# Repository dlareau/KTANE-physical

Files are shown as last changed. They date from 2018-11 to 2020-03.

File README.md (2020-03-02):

# KTANE-physical
A physical version of the game "Keep Talking and Nobody Explodes". 
Not a real bomb.

## Update: 3/2/2020
I am currently making progress on Version 2 of KTANE-physical. There are some major under the hood things that need to be done (such as replacing DSerial and designing PCBs) before new progress can be made. The "most-working" commit for V1 is currently commit aa4ee07, which is what should be used for attempts at replicating V1. 

### Planned Modules

| Module Name | Sketched | Coded | Made |
| --- |:---:|:---:|:---:|
| Memory |:heavy_check_mark:|:heavy_check_mark:|:heavy_check_mark:|
| Simon Says |:heavy_check_mark:|:heavy_check_mark:|:heavy_check_mark:|
| Wires |:heavy_check_mark:|:heavy_check_mark:|:heavy_check_mark:|
| Morse Code |:heavy_check_mark:|:heavy_check_mark:|:heavy_check_mark:|
| The Button |:heavy_check_mark:| | |
| Maze | | | |
| Password |:heavy_check_mark:|:heavy_check_mark:| |
| Keypad (symbols) |:heavy_check_mark:| | |
| Switches |:heavy_check_mark:|:heavy_check_mark:|:heavy_check_mark:|
| Letter Keys |:heavy_check_mark:| | |
| Twobits |:heavy_check_mark:| | |
| Crazy Talk |:heavy_check_mark:| | |
| Connection Check |:heavy_check_mark:| | |
| Venting Gas | | | |
| Capacitor Discharge | | | |
| Knobs | | | |

The general plan is for each module to contain an ATmega328p which will handle 
running all of the local I/O and communicate with a controller module
(also an Atmega328p).

### Intermodule communication (DSerial)

Many modules need to act as an I2C master to display devices or sensors, and
an unfortunate number of display devices have locked I2C addresses. This means
that I2C isn't feasibly a possibility for intermodule communication. Desiring
a solution that didn't require running a dedicated wire from each module to the
controller module, I opted for a multidrop serial bus. 

The downside of a multidrop bus is that some form of arbitration is
needed to stop bus contention. This is solved by the DSerial library I wrote
for this project. The DSerial library implements a layer on top of any Arduino
[Stream](http://www.arduino.cc/reference/en/language/functions/communication/stream/) 
interface. The DSerial library operates with one master and many clients and 
in addition to managing bus contention, it makes a best effort to guarantee
that each message will be delivered to the desired client exactly once. To this
end, it implements message-level parity checking, a pre-defined number of 
retries upon failed delivery, and can determine which clients are alive on the
network.

Currently DSerial has two major limitations: 
- Due to being comprised of entirely non-blocking calls, it requires whatever 
is using it to periodically and continuously call the doSerial method.

- It currently only allows the transmission of bytes with values between 0x01
and 0x7F inclusive. Future implementations will hopefully allow for the
transmission of null bytes and bytes above 0x7F.

### Module behavior and templates

Common functionality across modules has been extracted out into the KTANECommon
library. The library handles the sending/receiving of strikes, solves and
configuration data between solvable modules and the controller module. The 
library also handles the controller waiting for modules to setup and the modules
easily querying various aspects of the configuration data. The KTANECommon
library suffers from the same upside/downside as the DSerial library in that it
requires the code to periodically and continuously call the interpretData
function. 

A template for modules can be found [here](modules/exampleModule/example.ino).

### The Hardware

The current iteration of the hardware is Version 1. V1 consists of one
controller module and up to five swappable, playable modules in a suitcase as
an enclosure. The modules connect to the main bus through directional 
male/female 4 pin plugs intended for LED strips. The major limiting factor
imposed by V1 is the 1.25" height limit on user interface protrusions needed
to allow the case to close.

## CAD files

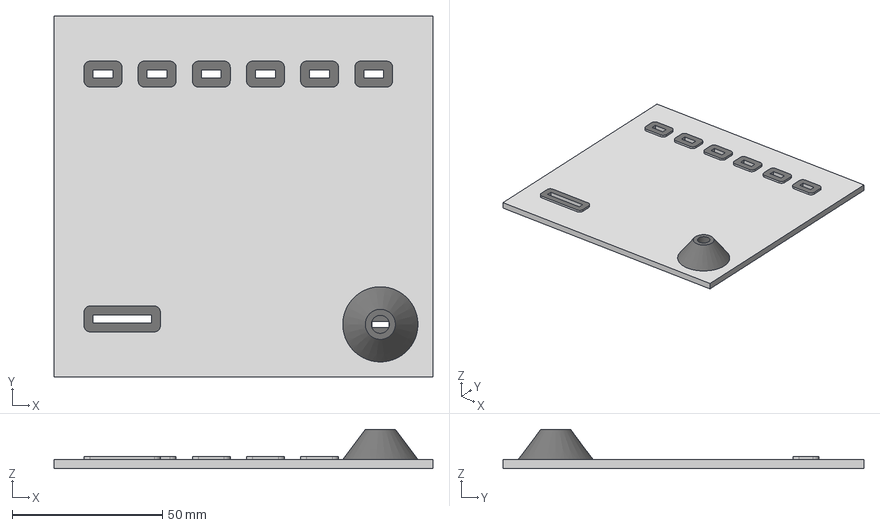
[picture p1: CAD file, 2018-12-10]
modules/basicWiresModule/front_plate_wires.stp
126.0 x 120.0 x 13.0 mm

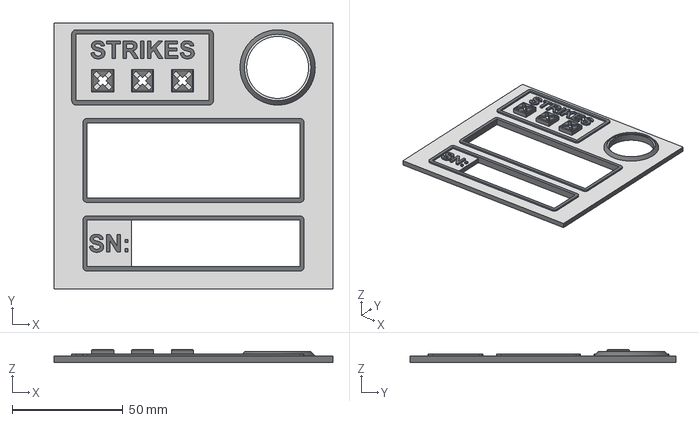
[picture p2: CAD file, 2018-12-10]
modules/controllerModule/front_plate_controller.stp
126.0 x 120.0 x 6.00 mm

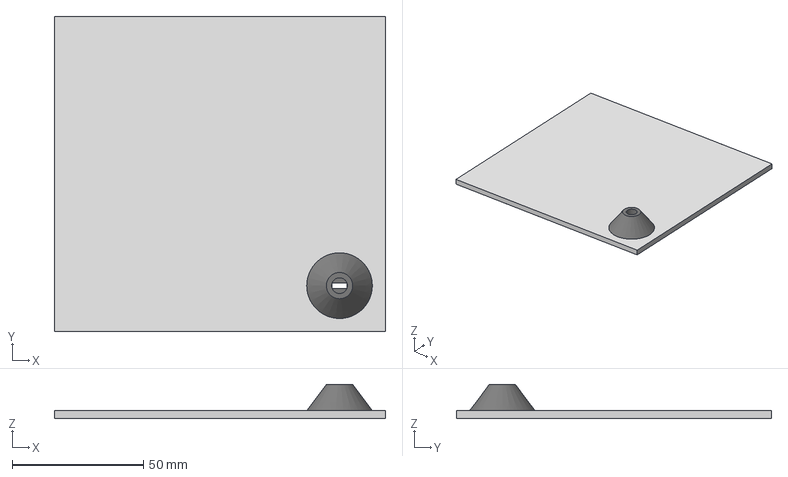
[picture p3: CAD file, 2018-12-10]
modules/exampleModule/front_face_example.stp
126.0 x 120.0 x 13.0 mm

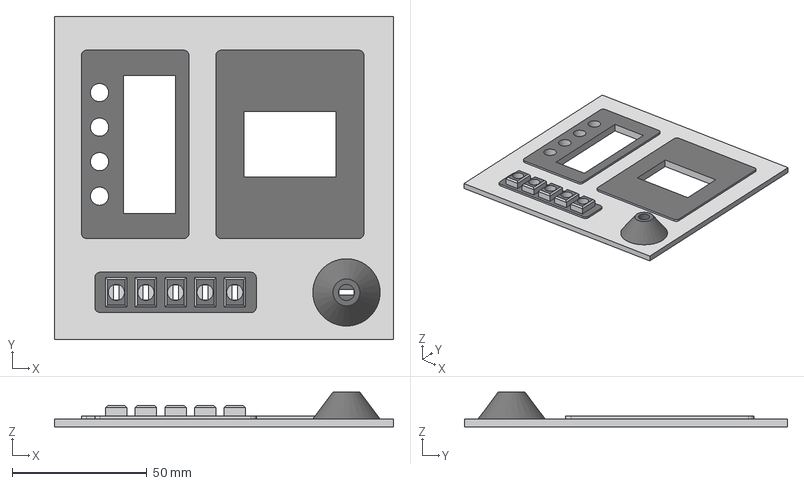
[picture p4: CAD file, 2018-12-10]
modules/memoryModule/front_plate_memory.stp
126.0 x 120.0 x 13.0 mm

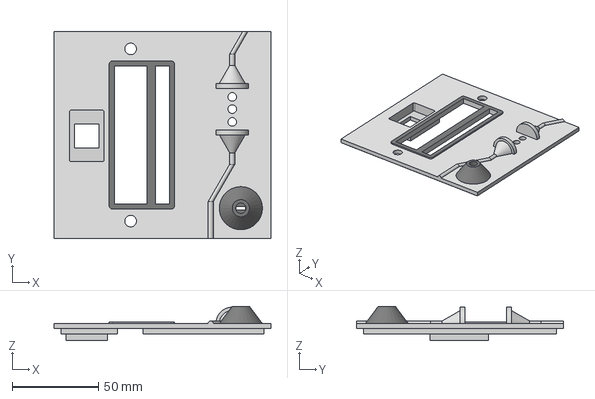
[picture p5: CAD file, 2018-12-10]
modules/morseCodeModule/front_plate_morse.stp
126.0 x 120.0 x 20.0 mm

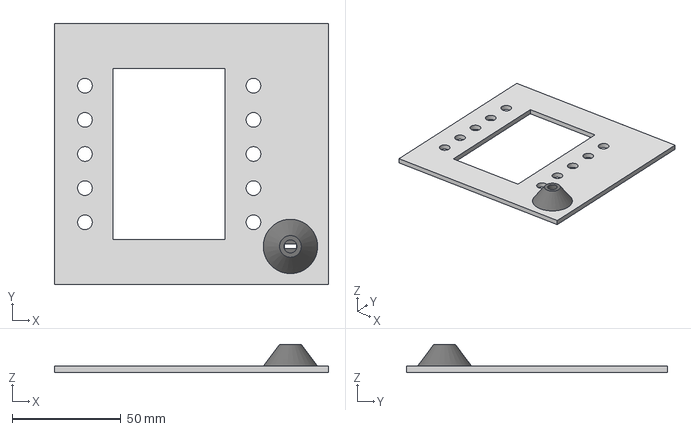
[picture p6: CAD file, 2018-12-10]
modules/passwordModule/front_plate_password.stp
126.0 x 120.0 x 13.0 mm

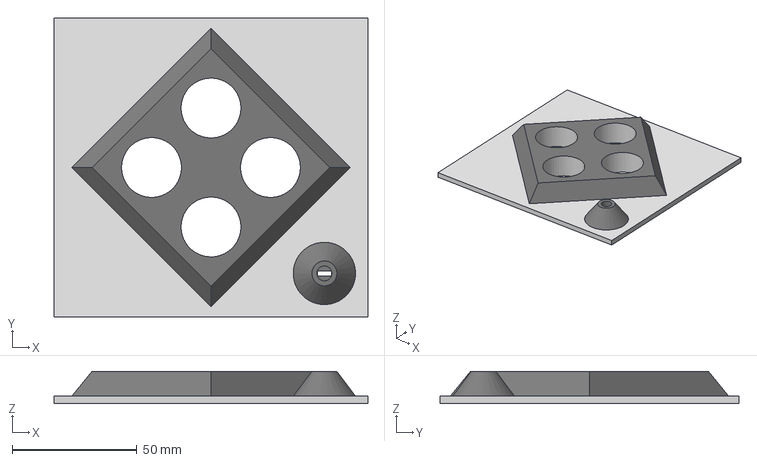
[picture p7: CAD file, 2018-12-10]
modules/simonSaysModule/front_plate_simon.stp
126.0 x 120.0 x 13.0 mm

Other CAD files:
modules/switchesModule/front_plate_switches.stp
modules/basicWiresModule/front_plate_wires.stl
modules/controllerModule/front_plate_controller.stl
modules/exampleModule/front_face_example.stl
modules/memoryModule/front_plate_memory.stl
modules/morseCodeModule/front_plate_morse.stl
modules/passwordModule/front_plate_password.stl
modules/simonSaysModule/front_plate_simon.stl
modules/switchesModule/front_plate_switches.stl

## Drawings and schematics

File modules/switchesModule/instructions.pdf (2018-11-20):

## On the Subject of Switches

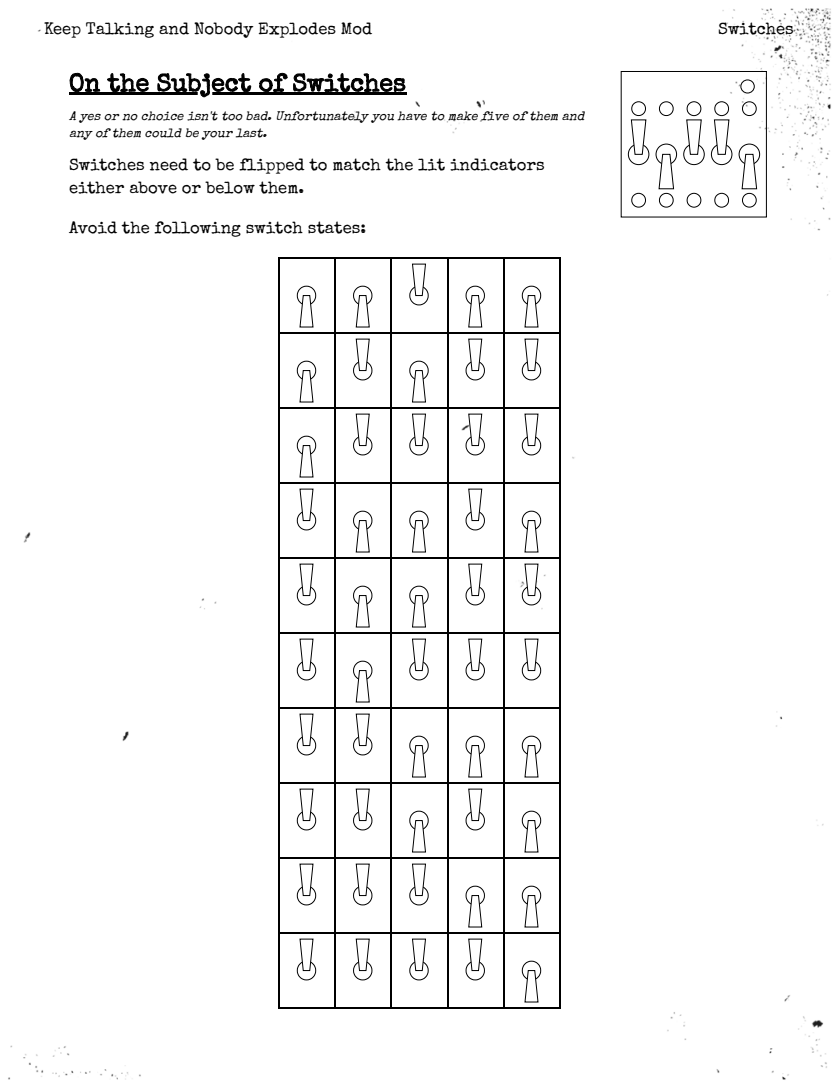
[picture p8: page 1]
Keep Talking and Nobody Explodes Mod; Switches

A yes or no choice isn't too bad. Unfortunately you have to make five of them and
any of them could be your last.
Switches need to be flipped to match the lit indicators
either above or below them.

Avoid the following switch states:

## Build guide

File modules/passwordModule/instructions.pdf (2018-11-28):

## On the Subject of Passwords

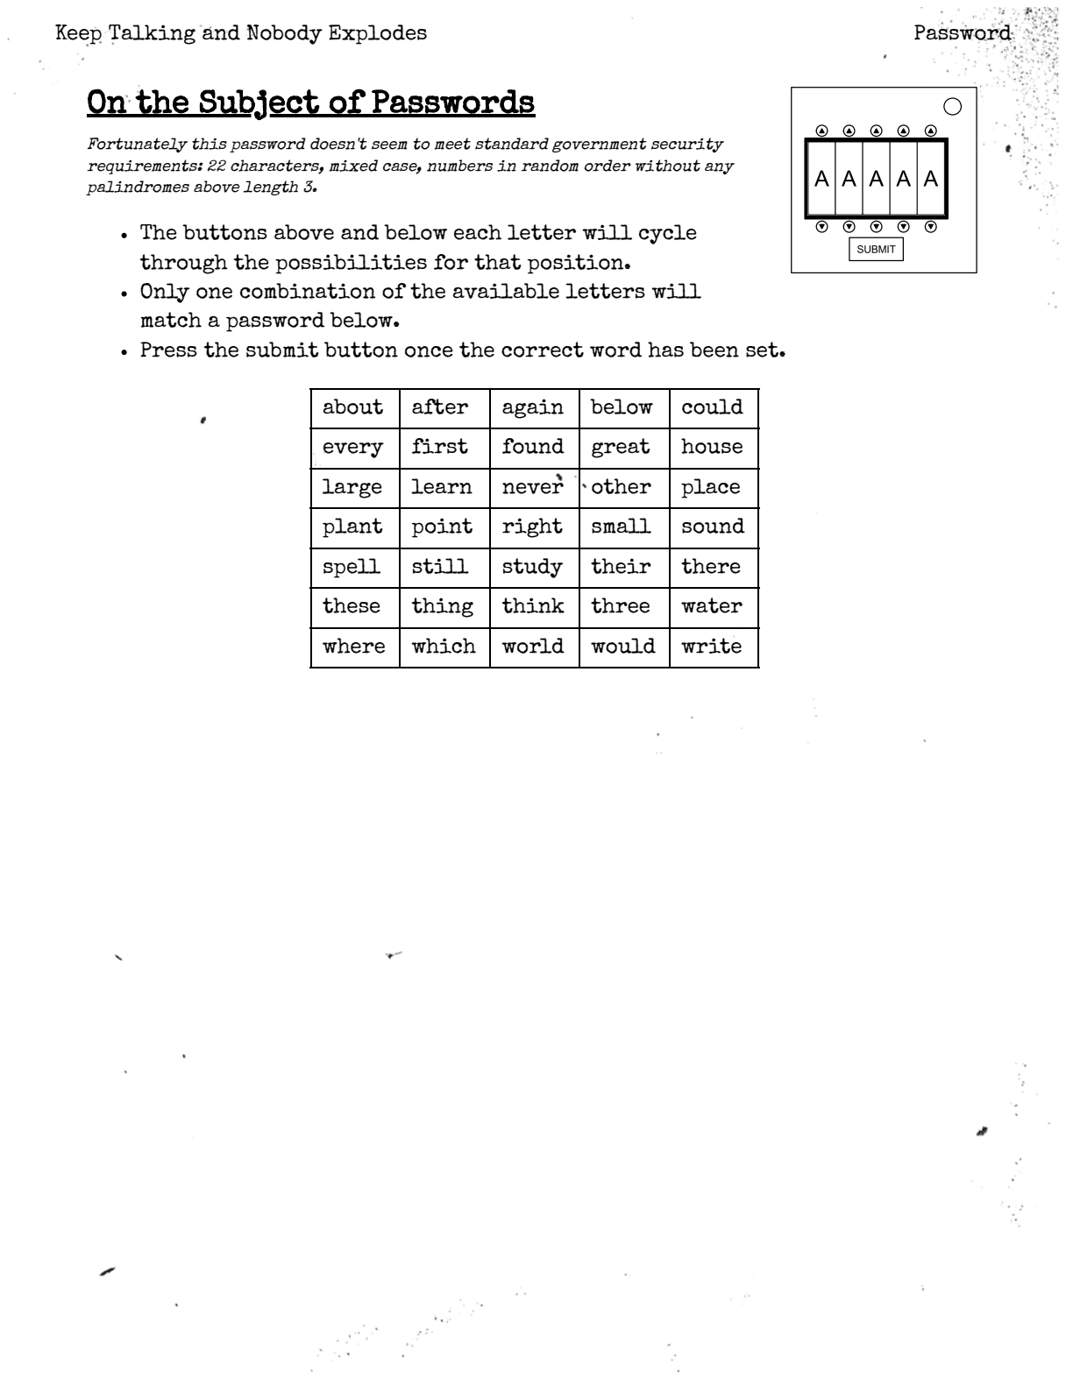
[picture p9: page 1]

Fortunately this password doesn't seem to meet standard government security requirements: 22 characters, mixed case, numbers in random order without any palindromes above length 3.

The buttons above and below each letter will cycle through the possibilities for that position.
Only one combination of the available letters will
match a password below.
Press the submit button once the correct word has been set.
about | after | again | below | could
every | first | found | great | house
large | learn | never | other | place
plant | point | right | small | sound
spell | still | study | their | there
these | thing | think | three | water
where | which | world | would | write
Keep Talking and Nobody Explodes | Password

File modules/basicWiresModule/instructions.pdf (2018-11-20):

## On the Subject of Wires

Wires are the lifeblood of electronics! Wait, no, electricity is the lifeblood. Wires are more like the arteries. The veins? No matter…

A wire module can have 3-6 wires on it.
Only the one correct wire needs to be cut to disarm the module.
Wire ordering begins with the first on the top.

3 wires:
If there are no red wires, cut the second wire.
Otherwise, if the last wire is white, cut the last wire.
Otherwise, if there is more than one blue wire, cut the last blue wire. Otherwise, cut the last wire.

4 wires:
If there is more than one red wire and the last digit of the serial number is odd, cut the last red wire.
Otherwise, if the last wire is yellow and there are no red wires, cut the first wire.
Otherwise, if there is exactly one blue wire, cut the first wire.
Otherwise, if there is more than one yellow wire, cut the last wire. Otherwise, cut the second wire.

5 wires:
If the last wire is black and the last digit of the serial number is odd, cut the fourth wire.
Otherwise, if there is exactly one red wire and there is more than one yellow wire, cut the first wire.
Otherwise, if there are no black wires, cut the second wire.
Otherwise, cut the first wire.

6 wires:
If there are no yellow wires and the last digit of the serial number is odd, cut the third wire.
Otherwise, if there is exactly one yellow wire and there is more than one white wire, cut the fourth wire.
Otherwise, if there are no red wires, cut the last wire.
Otherwise, cut the fourth wire.
Keep Talking and Nobody Explodes | Wires

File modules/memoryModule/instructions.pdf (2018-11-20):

## On the Subject of Memory

Memory is a fragile thing but so is everything else when a bomb goes off, so pay attention!

Press the correct button to progress the module to the next stage. Complete all stages to disarm the module. Pressing an incorrect button will reset the module back to stage 1.
Button positions are ordered from left to right.

Stage 1:
If the display is 1, press the button in the second position. If the display is 2, press the button in the second position. If the display is 3, press the button in the third position. If the display is 4, press the button in the fourth position.

Stage 2:
If the display is 1, press the button labeled "4".
If the display is 2, press the button in the same position as you pressed in stage 1. If the display is 3, press the button in the first position.
If the display is 4, press the button in the same position as you pressed in stage 1.

Stage 3:
If the display is 1, press the button with the same label you pressed in stage 2.
If the display is 2, press the button with the same label you pressed in stage 1. If the display is 3, press the button in the third position.
If the display is 4, press the button labeled "4".

Stage 4:
If the display is 1, press the button in the same position as you pressed in stage 1. If the display is 2, press the button in the first position.
If the display is 3, press the button in the same position as you pressed in stage 2. If the display is 4, press the button in the same position as you pressed in stage 2.

Stage 5:
If the display is 1, press the button with the same label you pressed in stage 1.
If the display is 2, press the button with the same label you pressed in stage 2. If the display is 3, press the button with the same label you pressed in stage 4. If the display is 4, press the button with the same label you pressed in stage 3.
Keep Talking and Nobody Explodes | Memory

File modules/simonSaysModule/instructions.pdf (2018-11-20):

## On the Subject of Simon Says

This is like one of those toys you played with as a kid where you have to match the pattern that appears, except this one is a knockoff that was probably purchased at a dollar store.

1. One of the four colored buttons will flash.
2. Using the correct table below, press the button with the
corresponding color.
3. The original button will flash, followed by another. Repeat this sequence in order using the color mapping.
4. The sequence will lengthen by one each time you correctly enter a sequence until the module is disarmed.

If the serial number contains a vowel:

Red Flash | Blue Flash | Green Flash | Yellow Flash
Button to press: | No Strikes | Blue | Red | Yellow | Green
| 1 Strike | Yellow | Green | Blue | Red
| 2+ Strikes | Green | Red | Yellow | Blue

If the serial number does not contain a vowel:

Red Flash | Blue Flash | Green Flash | Yellow Flash
Button to press: | No Strikes | Blue | Yellow | Green | Red
| 1 Strike | Red | Blue | Yellow | Green
| 2+ Strikes | Yellow | Green | Blue | Red
Keep Talking and Nobody Explodes | Simon Says

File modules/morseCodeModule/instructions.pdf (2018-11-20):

## On the Subject of Morse Code

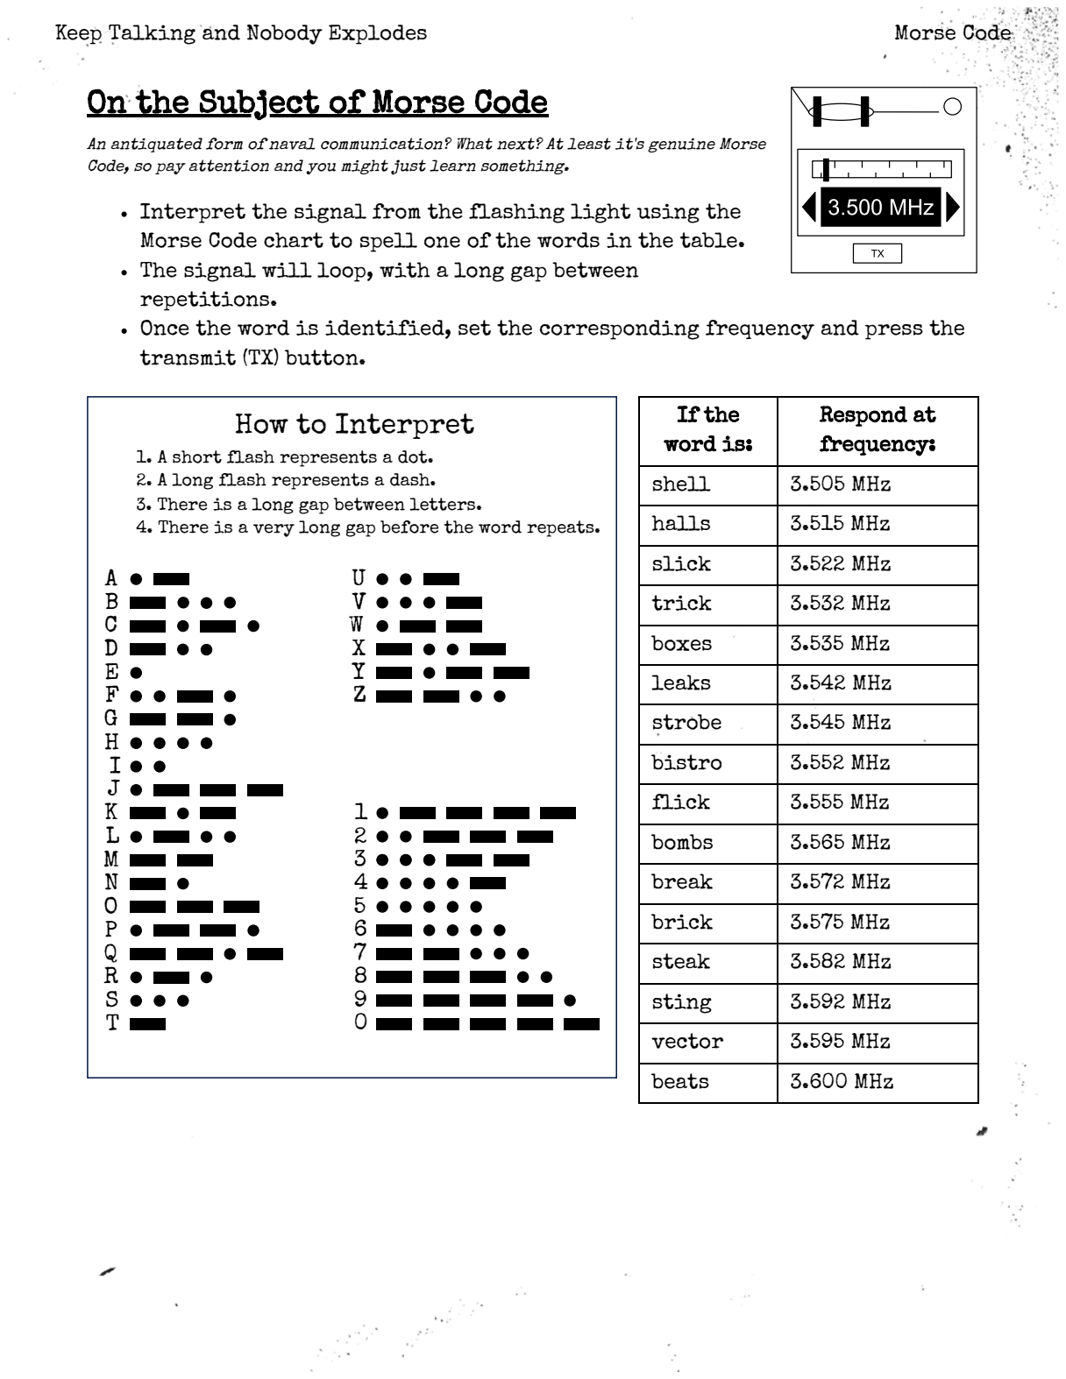
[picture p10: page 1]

## How to Interpret

1. A short flash represents a dot.
2. A long flash represents a dash.
3. There is a long gap between letters.
4. There is a very long gap before the word repeats.

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
An antiquated form of naval communication? What next? At least it's genuine Morse Code, so pay attention and you might just learn something.

Interpret the signal from the flashing light using the Morse Code chart to spell one of the words in the table.
The signal will loop, with a long gap between
repetitions.
Once the word is identified, set the corresponding frequency and press the transmit (TX) button.
If the word is: | Respond at frequency:
shell | 3.505 MHz
halls | 3.515 MHz
slick | 3.522 MHz
trick | 3.532 MHz
boxes | 3.535 MHz
leaks | 3.542 MHz
strobe | 3.545 MHz
bistro | 3.552 MHz
flick | 3.555 MHz
bombs | 3.565 MHz
break | 3.572 MHz
brick | 3.575 MHz
steak | 3.582 MHz
sting | 3.592 MHz
vector | 3.595 MHz
beats | 3.600 MHz
Keep Talking and Nobody Explodes | Morse Code

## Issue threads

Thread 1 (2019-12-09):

Any progress on this project?

cyberbit, 2019-12-09:
This is a neat project! A hardware version of KTANE is something I have been considering doing ever since watching the game for the first time many years ago. Are you still actively developing this? Any hints to the design of the hardware modules? I'd love to see a real working version!

dlareau, 2019-12-09:
Yeah, I took a long break on it, but I am actually just starting back up on the next version.
I don't know which method you stumbled upon this repo through, but if it wasn't the imgur album or my website, you can see the photos of V1 here: https://imgur.com/a/J6HdM0v#w1oaDi1 or here:

Basically all of the hardware for version 1 was point to point soldering, arduino nanos, and some stripboard where needed. (here is a photo of the back of 4 modules: https://photos.app.goo.gl/ooWz5mRqGPEx7vju6) Version 2 that I'm working on now will have PCBs, the design files for which will be included here once designed.

Version 1 was also very fragile, in that while things were swappable, yanking on a module would likely destroy it. Version 2 will also greatly improve upon the plug and play nature of the modules, making it so that anybody can swap out modules without the worry of breaking something.

If you have any other questions I'd love to chat.

cyberbit, 2019-12-13:
Thanks for the reply! That looks slick.

A part of me wonders about the feasibility of adding "parameterization" modules (battery slots, indicator lights, etc.) that are permanent around the edges of the device. I've got lots of other ideas spinning in my head but I can't nail them down.

dlareau, 2019-12-13:
Version 2 is already a bit ahead of you :)

While not quite in line with the original game layout, those 3 left-side boxes are for swappable items such as batteries, indicators, and ports.
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

olbrichj, 2020-02-05:
This really looks neat! I was looking at the game for my gaming round. Searching for something more immersive I found this.

Some remarks/ideas:
- The case and modules could be 3d printed. This would stabilize the module structure and improve swappability
- Will there be a serialnumber display at the side?

dlareau, 2020-02-06:
Thanks!

Replies in order:
- Serial number on the side was harder, so I ended up putting it in the extra space of the master/timer module, you can see it in [the gallery](https://imgur.com/a/J6HdM0v#w1oaDi1).
- There will be the option to connect multiple full units together, because of the way I've decided to architect things, the whole system runs off of a 4 wire bus that provides power and data, meaning hooking up a whole second case would be as easy as connecting those 4 wires between two cases. What connector that uses and where it will be haven't been sorted out yet.
- This project was meant to mimic the game and it's feel as much as possible. To that end, the modules were made to be in scale of the game by comparing against things like the ports/batteries on the side of the case. Plus, I can say from experience that things turned out well, when playing all of the elements felt accurate and very fun to interact with. Lastly, turns out I needed a lot of that space for electronics anyway, so it was all good.
- Similar to the above point, I was aiming for accuracy, so the 2x3 layout of the game felt right. The good news is that v2 is much more modular and includes 3d prints for both the module and the "module shell" which the module nestles into, so if someone else wanted to it would be really easy to just design a different holder for a bunch of module shells. Plus, I always imagined that if you wanted more than the 6+3, you could just hook up another case like talked about above.

rubenvt, 2020-04-17:
Great job done! I love this project and think the V2 with PCB would be great, because I have no idea how I would accomplish making V1 at this moment without a good diagram for each module to know where to connect wires to and which components to use :-) if you have any details about it, it would make my day. keep up the good work

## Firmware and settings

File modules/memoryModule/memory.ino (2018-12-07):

#include "DSerial.h"
#include "KTANECommon.h"
#include <NeoICSerial.h>

#define DATA_IN_PIN 11
#define LOAD_PIN 12
#define CLOCK_PIN 13
#define DISP_SINGLE(x,y) maxSingle((x), (y), LOAD_PIN, CLOCK_PIN, DATA_IN_PIN)

#define BUTTON1_PIN 14
#define BUTTON2_PIN 15
#define BUTTON3_PIN 16
#define BUTTON4_PIN 17

#define LED1_PIN 19
#define LED2_PIN 18
#define LED3_PIN 7
#define LED4_PIN 6
#define LED5_PIN 5

NeoICSerial serial_port;
DSerialClient client(serial_port, MY_ADDRESS);
KTANEModule module(client, 3, 4);

uint8_t bottom_nums[5][4];
uint8_t top_nums[5];
uint8_t buttons_to_press[5];
int stage = 0;

// Has 6 elements to stop overflow when you win
int led_pins[6] = {LED1_PIN, LED2_PIN, LED3_PIN, LED4_PIN, LED5_PIN, LED5_PIN};

byte max7219_reg_decodeMode  = 0x09;
byte max7219_reg_intensity   = 0x0a;
byte max7219_reg_scanLimit   = 0x0b;
byte max7219_reg_shutdown    = 0x0c;
byte max7219_reg_displayTest = 0x0f;

int constants[5] = {
  0b10111110, // 0
  0b00010010, // 1
  0b11011100, // 2
  0b11011010, // 3
  0b01110010 // 4
};

int digits[5] = {3, 8, 6, 5, 4};

uint8_t getIndexFromNumber(uint8_t *buttons, uint8_t num){
  for(int i = 0; i < 4; i++) {
    if(buttons[i] == num) {
      return i;
    }
  }
  return 255;
}

void updateDisplays() {
  DISP_SINGLE(5, constants[bottom_nums[stage][0]]);
  DISP_SINGLE(6, constants[bottom_nums[stage][1]]);
  DISP_SINGLE(8, constants[bottom_nums[stage][2]]);
  DISP_SINGLE(3, constants[bottom_nums[stage][3]]);
  DISP_SINGLE(4, constants[top_nums[stage]]);
  for(int i = 0; i < 5; i++) {
    digitalWrite(led_pins[i], LOW);
  }
  for(int i = 0; i <= stage; i++) {
    digitalWrite(led_pins[i], HIGH);
  }
}

void displayWaitingScreen() {

  // needs to delay for a total of 2500
  for(int i = 0; i < 5; i++) {
    DISP_SINGLE(digits[i], 0);
    delayWithUpdates(module, 100);
  }
  for(int i = 0; i < 15; i++){
    for(int j = 0; j < 5; j++) {
      DISP_SINGLE(digits[j], 1 << ((i+j)%7));
    }
    delayWithUpdates(module, 100);
  }
  for(int i = 0; i < 5; i++) {
    DISP_SINGLE(digits[i], 0);
  }
  delayWithUpdates(module, 500);
}

void generateRandomNumbers() {
  int r1, r2;
  uint8_t temp;
  for(int i = 0; i < 5; i++){
    bottom_nums[i][0] = 1;
    bottom_nums[i][1] = 2;
    bottom_nums[i][2] = 3;
    bottom_nums[i][3] = 4;

    for(int j = 0; j < 20; j++){
      r1 = random(0, 4);
      r2 = random(0, 4);
      temp = bottom_nums[i][r1];
      bottom_nums[i][r1] = bottom_nums[i][r2];
      bottom_nums[i][r2] = temp;
    }

    top_nums[i] = random(1,5);
  }

  switch(top_nums[0]) {
    case(1):
      buttons_to_press[0] = 1; // Second Position
      break;
    case(2):
      buttons_to_press[0] = 1; // Second Position
      break;
    case(3):
      buttons_to_press[0] = 2; // Third Position
      break;
    case(4):
      buttons_to_press[0] = 3; // Fourth Position
      break;
  }
  switch(top_nums[1]) {
    case(1):
      // Button labeled 4
      buttons_to_press[1] = getIndexFromNumber(bottom_nums[1], 4);
      break;
    case(2):
      buttons_to_press[1] = buttons_to_press[0]; // Same position as stage 1
      break;
    case(3):
      buttons_to_press[1] = 0; // First Position
      break;
    case(4):
      buttons_to_press[1] = buttons_to_press[0]; // Same position as stage 1
      break;
  }
  switch(top_nums[2]) {
    case(1):
      // Same label as stage 2
      buttons_to_press[2] = getIndexFromNumber(bottom_nums[2], bottom_nums[1][buttons_to_press[1]]);
      break;
    case(2):
      // Same label as stage 1
      buttons_to_press[2] = getIndexFromNumber(bottom_nums[2], bottom_nums[0][buttons_to_press[0]]);
      break;
    case(3):
      buttons_to_press[2] = 2;  // Third Position
      break;
    case(4):
      // Button labeled 4
      buttons_to_press[2] = getIndexFromNumber(bottom_nums[2], 4) ;
      break;
  }
  switch(top_nums[3]) {
    case(1):
      buttons_to_press[3] = buttons_to_press[0]; // Same position as stage 1
      break;
    case(2):
      buttons_to_press[3] = 0;  // First Position
      break;
    case(3):
      buttons_to_press[3] = buttons_to_press[1]; // Same position as stage 2
      break;
    case(4):
      buttons_to_press[3] = buttons_to_press[1]; // Same position as stage 2
      break;
  }
  switch(top_nums[4]) {
    case(1):
      // Same label as stage 1
      buttons_to_press[4] = getIndexFromNumber(bottom_nums[4], bottom_nums[0][buttons_to_press[0]]);
      break;
    case(2):
      // Same label as stage 2
      buttons_to_press[4] = getIndexFromNumber(bottom_nums[4], bottom_nums[1][buttons_to_press[1]]);
      break;
    case(3):
      // Same label as stage 3
      buttons_to_press[4] = getIndexFromNumber(bottom_nums[4], bottom_nums[2][buttons_to_press[3]]);
      break;
    case(4):
      // Same label as stage 4
      buttons_to_press[4] = getIndexFromNumber(bottom_nums[4], bottom_nums[3][buttons_to_press[2]]);
      break;
  }

  // for(int i = 0; i < 5; i++) {
  //   Serial.println("");
  //   Serial.println("");
  //   Serial.println(top_nums[i]);
  //   Serial.println(buttons_to_press[i]);
  //   for(int j = 0; j < 4; j++){
  //     Serial.print(bottom_nums[i][j]);
  //   }
  // }
}

void setup() {
  serial_port.begin(19200);
  Serial.begin(19200);

  pinMode(DATA_IN_PIN, OUTPUT);
  pinMode(LOAD_PIN, OUTPUT);
  pinMode(CLOCK_PIN, OUTPUT);
  pinMode(BUTTON1_PIN, INPUT);
  pinMode(BUTTON2_PIN, INPUT);
  pinMode(BUTTON3_PIN, INPUT);
  pinMode(BUTTON4_PIN, INPUT);
  pinMode(LED1_PIN, OUTPUT);
  pinMode(LED2_PIN, OUTPUT);
  pinMode(LED3_PIN, OUTPUT);
  pinMode(LED4_PIN, OUTPUT);
  pinMode(LED5_PIN, OUTPUT);

  DISP_SINGLE(max7219_reg_scanLimit, 0x07);
  DISP_SINGLE(max7219_reg_decodeMode, 0x00);  // using an led matrix (not digits)
  DISP_SINGLE(max7219_reg_shutdown, 0x01);    // not in shutdown mode
  DISP_SINGLE(max7219_reg_displayTest, 0x00); // no display test
   for (int e=1; e<=8; e++) {    // empty registers, turn all LEDs off
    DISP_SINGLE(e,0);
  }
  DISP_SINGLE(max7219_reg_intensity, 0x0f & 0x0f); // the first 0x0f is the value you can set

  while(!module.getConfig()){
    module.interpretData();
  }

  randomSeed(config_to_seed(module.getConfig()));

  // Generate numbers
  generateRandomNumbers();
  updateDisplays();

  module.sendReady();
}

void loop() {
  int button_pressed = -1;

  module.interpretData();

  if(!module.is_solved) {
    if(digitalRead(BUTTON1_PIN)) {
      button_pressed = 0;
    } else if(digitalRead(BUTTON2_PIN)) {
      button_pressed = 1;
    } else if(digitalRead(BUTTON3_PIN)) {
      button_pressed = 2;
    } else if(digitalRead(BUTTON4_PIN)) {
      button_pressed = 3;
    }

    if(button_pressed != -1) {
      if(button_pressed == buttons_to_press[stage]) {
        stage++;
      } else {
        stage = 0;
        generateRandomNumbers();
        module.strike();
      }
      if(stage == 5){
        module.win();
      } else {
      displayWaitingScreen();
      updateDisplays();
      }
    }
  }

}

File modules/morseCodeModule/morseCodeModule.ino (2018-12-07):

#include "DSerial.h"
#include "KTANECommon.h"
#include <NeoICSerial.h>
#include "morse.h"
#include <Wire.h>
#include <SPI.h>
#include <Adafruit_GFX.h>
#include "Adafruit_LEDBackpack.h"

#define BUTTON_R_PIN A3
#define BUTTON_L_PIN A2
#define BUTTON_TX_PIN A1
#define MORSE_LED_PIN 5

NeoICSerial serial_port;
DSerialClient client(serial_port, MY_ADDRESS);
KTANEModule module(client, 3, 4);
Adafruit_7segment matrix = Adafruit_7segment();

int goal_freq;
int selected_freq = 0;
uint8_t morse_bits[8];
int morse_index;
int morse_length;

unsigned long last_char_time = 0;

unsigned long last_button_time = 0;

void setMorseBit(uint8_t *bits, int index, int val) {
  uint8_t and_mask, or_mask;
  and_mask = ~(1 << (index % 8));
  or_mask = ((!!val) << (index % 8));
  bits[index/8] = (bits[index/8] & and_mask) | or_mask;
}

int getMorseBit(uint8_t *bits, int index) {
  uint8_t mask;
  mask = (1 << (index % 8));
  return bits[index/8] & mask;
}

void setup() {
  serial_port.begin(19200);
  Serial.begin(19200);
  matrix.begin(0x70);
  
  while(!module.getConfig()){
    module.interpretData();
  }
  randomSeed(config_to_seed(module.getConfig()));
  pinMode(BUTTON_L_PIN, INPUT_PULLUP);
  pinMode(BUTTON_R_PIN, INPUT_PULLUP);
  pinMode(BUTTON_TX_PIN, INPUT_PULLUP);
  pinMode(MORSE_LED_PIN, OUTPUT);

  morse_index = 0;
  goal_freq = random(0, 16);
  for(unsigned int i = 0; i < strlen(words[goal_freq]); i++) {
    char *morse_desc = morse[words[goal_freq][i] - 'a'];
    for(unsigned int j = 0; j < strlen(morse_desc); j++) {
      if(morse_desc[j] == '.') {
        setMorseBit(morse_bits, morse_index++, 1);
        setMorseBit(morse_bits, morse_index++, 0);
      } else if(morse_desc[j] == '-') {
        setMorseBit(morse_bits, morse_index++, 1);
        setMorseBit(morse_bits, morse_index++, 1);
        setMorseBit(morse_bits, morse_index++, 1);
        setMorseBit(morse_bits, morse_index++, 0);
      }
    }
    setMorseBit(morse_bits, morse_index++, 0);
    setMorseBit(morse_bits, morse_index++, 0);
  }
  setMorseBit(morse_bits, morse_index++, 0);
  setMorseBit(morse_bits, morse_index++, 0);
  setMorseBit(morse_bits, morse_index++, 0);
  setMorseBit(morse_bits, morse_index++, 0);
  morse_length = morse_index;
  morse_index = 0;

  module.sendReady();
}

void doMorse() {
  Serial.println("morse");
  if(millis() - last_char_time >= DOT_TIME){
    last_char_time = millis();
    digitalWrite(MORSE_LED_PIN, getMorseBit(morse_bits, morse_index));
    morse_index = (morse_index + 1) % morse_length;
  }
}

void loop() {
  module.interpretData();
  doMorse();

  if(!module.is_solved){
    if(!digitalRead(BUTTON_L_PIN) && (millis() - last_button_time > 250)) {
      last_button_time = millis();
      selected_freq--;
      if(selected_freq < 0) {
        selected_freq = 0;
      }
    }
    if(!digitalRead(BUTTON_R_PIN) && (millis() - last_button_time > 250)) {
      last_button_time = millis();
      selected_freq++;
      if(selected_freq > 15){
        selected_freq = 15;
      }
    }


    matrix.writeDigitNum(0, 3);
    matrix.writeDigitNum(1, freqs[selected_freq][0] - '0');
    matrix.writeDigitNum(3, freqs[selected_freq][1] - '0');
    matrix.writeDigitNum(4, freqs[selected_freq][2] - '0');
    matrix.writeDisplay();

    if(!digitalRead(BUTTON_TX_PIN)) {
      if(selected_freq == goal_freq) {
        module.win();
      } else {
        digitalWrite(MORSE_LED_PIN, LOW);
        module.strike();
      }
    }
  }
}

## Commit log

2018-06-28 switched to using arduino-makefile
2018-06-28 Switched dserial lib to using a pointer for the stream object
2018-06-29 Added sample test module
2018-07-01 Switched DSerial Library to FIFO queue
2018-07-05 Added first version of switches module
2018-07-17 Updated Simon Says to check all buttons in a sequence
2018-11-20 finalized switches code
2018-11-20 test of stls
    [front_plate_simon.stl]
2018-11-28 fixed morse code module to use i2c
    [morseCodeModule.ino]
2018-11-28 Changed makefile to work with newest arduino version
2018-11-29 Fix wire colors for basicWires
    [basicWires.ino]
2018-12-01 Fixed bug in memory module
    [memory.ino]
2018-12-01 Simon says lights now turns off lights after reset
    [simonSays.ino]
2018-12-01 Hopefully fixed switches issue
    [switches.ino]
2018-12-01 switches should no longer start with incorrect state
    [switches.ino]
2018-12-01 hopefully fixed random strike issue with wiresModule
    [basicWires.ino]
2018-12-06 bug fixes in switches and wires
    [basicWires.ino, switches.ino]
2018-12-07 Experimental simon says fixes
    [simonSays.ino]
2018-12-10 Added 3d models of all front plates
    [front_face_example.stl, front_face_example.stp, front_plate_controller.stl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]
2018-12-14 KTANECommon now includes debug printing for DSerial
2019-11-11 Update README.md
    Updated broken link to arduino website.
2019-12-16 Fixed OOB access bug, added print function
